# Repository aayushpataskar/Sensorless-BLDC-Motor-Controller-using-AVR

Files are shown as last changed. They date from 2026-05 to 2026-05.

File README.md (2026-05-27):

# Sensorless-BLDC-Motor-Controller-using-AVR
Bare-metal sensorless BLDC motor controller using AVR microcontrollers implementing 6-step trapezoidal commutation, back-EMF zero-crossing detection, PID speed control, PWM generation, current limiting, UVLO protection, and hardware-level motor control architecture.

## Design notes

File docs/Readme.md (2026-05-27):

# Sensorless BLDC Motor Controller — AVR / Arduino UNO

<p align="center">
  ESC Banner
</p>

<p align="center">
  
  
  
  
  
</p>

---

## Overview

This project is a **complete, sensorless Brushless DC (BLDC) motor controller** (Electronic Speed Controller — ESC) implemented from scratch on an **ATmega328P (Arduino UNO R3)** using **bare-metal AVR C** — no Arduino HAL, no motor-control library, no shortcuts.

The controller uses **6-step trapezoidal commutation**, **back-EMF (BEMF) zero-crossing detection** for rotor position sensing, a **PI speed control loop**, and a suite of hardware protection features — all coordinated by a single **interrupt-driven control loop running at ~1 kHz**.

The hardware is designed in **KiCad 9.0** and centres around three **IR2101 half-bridge gate drivers**, six **IRF6617 N-channel MOSFETs**, and an **LM393 dual comparator** for BEMF sensing conditioning.

---

## Key Features

| Feature | Implementation |
|---|---|
| Motor type | 3-phase sensorless BLDC |
| Commutation | 6-step trapezoidal |
| Rotor sensing | Back-EMF zero-crossing detection (software ADC) |
| Gate driving | IR2101 (bootstrap half-bridge × 3 phases) |
| PWM generation | AVR Timer1 (Fast PWM 8-bit) + Timer2 |
| Control loop | Timer0 CTC ISR @ ~1 kHz |
| Speed control | PI controller (proportional + integral) |
| Current limiting | ADC-based with PWM duty-cycle back-off |
| UVLO | Vbus ADC monitoring with hard-fault latch |
| Blanking time | Software blanking window post-commutation |
| Startup | Open-loop forced commutation ramp |
| Schematic | KiCad 9.0 |

---

## Repository Structure

```
sensorless-bldc-avr/
│
├── firmware/
│   └── ESC_using_Arduino.ino       # Main firmware (bare-metal AVR C)
│
├── hardware/
│   ├── esc_using_arduino_uno.kicad_pro
│   └── esc_using_arduino_uno.kicad_sch
│
├── docs/
│   ├── project_overview.md
│   ├── hardware_architecture.md
│   ├── firmware_architecture.md
│   ├── pwm_generation.md
│   ├── adc_and_backemf.md
│   ├── six_step_commutation.md
│   ├── pid_speed_control.md
│   ├── protection_features.md
│   ├── interrupt_architecture.md
│   ├── state_machine.md
│   ├── tuning_and_debugging.md
│   └── future_work.md
│
├── README.md
└── LICENSE
```

---

## Hardware Summary

| Component | Part | Quantity | Role |
|---|---|---|---|
| Microcontroller | Arduino UNO R3 (ATmega328P) | 1 | Control, PWM, ADC |
| Gate driver | IR2101 | 3 | High/low-side MOSFET driving |
| Power MOSFET | IRF6617 | 6 | H-bridge switching (3 half-bridges) |
| Comparator | LM393 (dual) | 1–2 | BEMF signal conditioning |
| Bootstrap diode | 1N5817 (Schottky) | 3 | IR2101 bootstrap charging |
| Gate resistor | 10 Ω | 6 | Switching transition control |
| Pull-down | 10 kΩ | 6 | Gate pull-down |
| Bootstrap cap | 100 nF | 3 | IR2101 bootstrap supply |
| Bulk capacitor | 2.2 mF | 1 | Vbus decoupling |
| Phase resistors | R_Small | 9 | Voltage divider for BEMF sensing |

> See [`docs/hardware_architecture.md`](docs/hardware_architecture.md) for the full schematic walk-through and BOM.

---

## Pin Mapping

| Arduino Pin | AVR Register | Signal | Direction |
|---|---|---|---|
| D9 (OC1A) | PB1 | Phase A — High Side (AH) | Output / PWM |
| D10 (OC1B) | PB2 | Phase B — High Side (BH) | Output / PWM |
| D11 (OC2A) | PB3 | Phase C — High Side (CH) | Output / PWM |
| D4 | PD4 | Phase A — Low Side (AL) | Output / GPIO |
| D7 | PD7 | Phase B — Low Side (BL) | Output / GPIO |
| D8 | PB0 | Phase C — Low Side (CL) | Output / GPIO |
| A0 | ADC0 | Phase A BEMF | Input / ADC |
| A1 | ADC1 | Phase B BEMF | Input / ADC |
| A2 | ADC2 | Phase C BEMF | Input / ADC |
| A3 | ADC3 | Phase current sense | Input / ADC |
| A4 | ADC4 | Vbus voltage sense | Input / ADC |

---

## Quick Start

### Prerequisites

- Arduino IDE 2.x or avr-gcc toolchain
- KiCad 9.0 (for schematic viewing/editing)
- A 3-phase BLDC motor (suitable for target Vbus)

### Building & Flashing

```bash
# Using Arduino IDE
# Open firmware/ESC_using_Arduino.ino → Select "Arduino UNO" → Upload

# Using avr-gcc directly
avr-gcc -mmcu=atmega328p -DF_CPU=16000000UL -O2 -o ESC.elf ESC_using_Arduino.ino
avr-objcopy -O ihex ESC.elf ESC.hex
avrdude -c arduino -p m328p -P /dev/ttyUSB0 -b 115200 -U flash:w:ESC.hex
```

### Key Configuration Parameters

Edit the `CONFIG` block at the top of `ESC_using_Arduino.ino`:

```c
#define NEUTRAL_ADC        512   // Virtual neutral point (midscale)
#define BLANKING_TICKS       5   // ISR ticks to suppress BEMF after commutation
#define CURRENT_LIMIT_ADC  650   // ADC counts → current trip threshold
#define MIN_PWM_DUTY        20   // Minimum duty cycle (stall prevention)
#define MAX_PWM_DUTY       180   // Maximum duty cycle (out of 255)
#define VBUS_MIN_ADC       420   // UVLO trip — Vbus too low
#define START_PERIOD       400   // Open-loop start commutation period (ticks)
#define TARGET_PERIOD      120   // Target commutation period after ramp
float Kp = 0.6f;
float Ki = 20.0f;
float target_speed = 200.0f;    // Desired speed setpoint (arbitrary units)
```

---

## Documentation Index

| Document | Contents |
|---|---|
| [Project Overview](docs/project_overview.md) | System goals, architecture summary, design decisions |
| [Hardware Architecture](docs/hardware_architecture.md) | Gate driver topology, MOSFET selection, BEMF sensing, BOM |
| [Firmware Architecture](docs/firmware_architecture.md) | Code structure, module breakdown, ISR/main interaction |
| [PWM Generation](docs/pwm_generation.md) | Timer1/Timer2 configuration, fast PWM, duty cycle update |
| [ADC & Back-EMF Sensing](docs/adc_and_backemf.md) | ADC configuration, floating phase selection, ZC detection |
| [6-Step Commutation](docs/six_step_commutation.md) | Trapezoidal theory, commutation table, timing diagram |
| [PID Speed Control](docs/pid_speed_control.md) | Speed estimation, PI equations, anti-windup, tuning |
| [Protection Features](docs/protection_features.md) | UVLO, current limiting, blanking time, fault latch |
| [Interrupt Architecture](docs/interrupt_architecture.md) | Timer0 ISR flow, ISR execution budget, latency analysis |
| [State Machine](docs/state_machine.md) | System states, transitions, startup sequence |
| [Tuning & Debugging](docs/tuning_and_debugging.md) | Parameter tuning guide, common failure modes |
| [Future Work](docs/future_work.md) | STM32 migration, FOC, SVPWM, hardware sensors |

---

## Suggested GitHub Topics

`bldc-motor-controller` · `esc` · `sensorless-bldc` · `back-emf` · `zero-crossing-detection` · `avr` · `atmega328p` · `arduino` · `bare-metal` · `motor-control` · `trapezoidal-commutation` · `pwm` · `pid-controller` · `kicad` · `ir2101` · `embedded-c` · `power-electronics`

---

## License

MIT License — see [LICENSE](LICENSE) for details.

---

## Author

Developed as an embedded systems engineering portfolio project.  
Platform: ATmega328P (Arduino UNO R3) · Schematic: KiCad 9.0 · Firmware: Bare-metal AVR C

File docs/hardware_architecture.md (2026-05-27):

# Hardware Architecture

## 1. Overview

The power stage implements a **three-phase voltage-source inverter** using six N-channel MOSFETs arranged as three half-bridges. Each half-bridge drives one motor phase (A, B, C). High-side gate driving is handled by three **IR2101** bootstrap half-bridge gate driver ICs, which solve the floating high-side drive problem without requiring an isolated power supply. BEMF voltage sensing is routed through resistor dividers to the ATmega328P's ADC inputs, with the **LM393** dual comparator available for hardware-assisted zero-crossing detection.

---

## 2. Three-Phase Half-Bridge Topology

```
        Vbus (+)
          │
    ┌─────┼─────┬─────────────┐
    │     │     │             │
   [AH]  [BH]  [CH]           │   (High-side MOSFETs — IRF6617)
    │     │     │             │
   PhA   PhB   PhC ──── BLDC Motor (star-wound)
    │     │     │             │
   [AL]  [BL]  [CL]           │   (Low-side MOSFETs — IRF6617)
    │     │     │             │
    └─────┴─────┴─────────────┘
          │
        GND (-)
```

The motor is assumed to be **star (Y) wound**, producing a virtual neutral point at the junction of the three stator windings. Two phases are driven at any instant (one high, one low) while the third phase floats — this floating phase carries the back-EMF signal used for rotor position estimation.

---

## 3. Gate Driver — IR2101

### 3.1 Why a Gate Driver Is Needed

Power MOSFETs require a gate-to-source voltage (V_GS) of typically 10–12 V to turn on fully into the low-resistance triode region. For low-side MOSFETs, the source is tied to GND, so a logic-level 5 V signal is insufficient (and would result in a partially-on MOSFET with high conduction losses and thermal stress). For high-side MOSFETs, the source sits at the phase output voltage — during conduction it can approach Vbus — so the gate must be driven to V_GS(th) _above_ a floating reference, which the microcontroller cannot do directly.

The **IR2101** solves both problems. It is a monolithic half-bridge driver providing:

- A **low-side output (LO)** referenced to GND — drives the low-side MOSFET gate
- A **high-side output (HO)** referenced to the switch node (VS pin) — drives the high-side MOSFET gate using a bootstrap-charged floating supply

### 3.2 Bootstrap Operation

The bootstrap capacitor (100 nF) is charged through the **1N5817 Schottky diode** when the low-side MOSFET is on: current flows from VCC (5 V) → diode → bootstrap capacitor → VS (switch node at ≈ GND). When the low-side turns off and the high-side is commanded on, the bootstrap capacitor's charged voltage rides up with the switch node and provides the floating supply (V_B) for the high-side driver output. The Schottky diode (low forward voltage, fast recovery) prevents the bootstrap capacitor from discharging back into the VCC rail when VS rises.

```
           VCC (+5V)
              │
             [D: 1N5817 Schottky]
              │
              ├──── VB (IR2101 bootstrap supply)
              │
             [C_boot: 100 nF]
              │
         VS ──┴──── Switch Node (Phase Output)
```

### 3.3 Dead Time

The IR2101 includes internal dead time between its HO and LO outputs, preventing simultaneous conduction of both MOSFETs in a half-bridge (shoot-through). The firmware's `all_off()` function adds a software-level dead band by turning all switches off before applying the next commutation state.

### 3.4 Input Logic

The IR2101 accepts two independent inputs (HIN and LIN) from the microcontroller:

- **HIN** — connected to the PWM output of the corresponding timer channel (OC1A, OC1B, OC2A)
- **LIN** — connected to a GPIO pin (PD4, PD7, PB0) driven directly

The firmware controls whether PWM is active on a given high-side output by enabling or disabling the timer compare output mode bits (`COM1A1`, `COM1B1`, `COM2A1`). When disabled, the pin reverts to GPIO low, which turns off the high-side driver.

---

## 4. Power MOSFETs — IRF6617

The **IRF6617** is an N-channel MOSFET in a DirectFET package. Key parameters relevant to this design:

| Parameter | Value |
|---|---|
| V_DS (max) | 25 V |
| I_D (continuous) | 13 A |
| R_DS(on) @ V_GS = 10 V | ~11 mΩ |
| Gate charge (Q_g) | ~18 nC |
| Package | DirectFET (compact, low-inductance) |

Six devices are used: three high-side (AH, BH, CH) and three low-side (AL, BL, CL).

Gate resistors (R_Small, typically 10 Ω) in series with each gate limit the gate current inrush and control the switching transition speed, reducing EMI and voltage overshoot at the cost of slightly slower switching transitions. Pull-down resistors (10 kΩ) ensure the gate is held low when the driver output is high-impedance (e.g., during startup before the driver IC is enabled).

---

## 5. BEMF Sensing Network

### 5.1 Resistor Divider

Motor phase voltages during operation swing from 0 V to Vbus. The ATmega328P ADC input is limited to 0–5 V (AVCC reference). A resistor divider scales the phase voltage to a safe ADC input range. Three identical dividers (one per phase) feed ADC channels 0, 1, and 2.

```
Phase Voltage (0 → Vbus)
        │
       [R_top]
        │
        ├──── ADC Input (0 → 5 V scaled)
        │
       [R_bot]
        │
       GND
```

The virtual neutral point for zero-crossing comparison is set in firmware as `NEUTRAL_ADC = 512`, corresponding to the midpoint of the 10-bit ADC range (2.5 V on the divided input, which corresponds to Vbus/2 on the phase).

### 5.2 LM393 Comparator Path

The **LM393** dual comparator is schematically connected to compare the BEMF-divided phase voltage against the virtual neutral. Its open-collector output can be connected to a microcontroller GPIO/INT pin for hardware interrupt-driven zero-crossing detection. In the current firmware, this path is not used — zero-crossing is detected in software via the ADC — but the hardware is in place for an upgrade to comparator-interrupt detection (see [`future_work.md`](future_work.md)).

---

## 6. Current Sensing

A shunt resistor in the low-side current path produces a voltage proportional to motor current. This voltage is routed to **ADC channel 3**. The firmware reads this channel each ISR tick and reduces the PWM duty cycle if the ADC count exceeds `CURRENT_LIMIT_ADC = 650`.

> **Note:** A production design would use a dedicated current-sense amplifier (e.g., INA219, INA240) to amplify the small shunt voltage and provide common-mode rejection. The current sensing in this design is approximate.

---

## 7. Vbus Sensing (UVLO)

A resistor divider from the Vbus rail to GND feeds **ADC channel 4**. The firmware monitors this continuously and asserts a fault latch if the reading falls below `VBUS_MIN_ADC = 420`, corresponding to an under-voltage condition on the bus. This protects the power electronics and prevents erratic operation caused by a sagging supply.

---

## 8. Decoupling and Filtering

A bulk electrolytic capacitor (2.2 mF, referenced as `C2.2MF` in the schematic) is placed across the Vbus supply. This capacitor:

- Absorbs current spikes during MOSFET switching transitions
- Reduces ripple on Vbus caused by motor commutation currents
- Stores energy during regenerative braking pulses

Small ceramic decoupling capacitors (100 nF) are placed on each IR2101 VCC and VB pin for high-frequency noise bypass.

---

## 9. Bill of Materials (BOM)

| Reference | Value / Part | Description | Qty |
|---|---|---|---|
| U1, U2, U3 | IR2101 | Half-bridge MOSFET gate driver | 3 |
| Q1–Q6 | IRF6617 | N-channel power MOSFET | 6 |
| U4 | LM393 | Dual voltage comparator | 1 |
| A1 | Arduino UNO R3 | ATmega328P control module | 1 |
| D1, D2, D3 | 1N5817 | Schottky bootstrap diode | 3 |
| C1, C2, C3 | 100 nF (ceramic) | Bootstrap capacitor | 3 |
| C4 | 2.2 mF (electrolytic) | Vbus bulk decoupling | 1 |
| R1–R6 | 10 Ω | Gate resistors | 6 |
| R7–R12 | 10 kΩ | Gate pull-downs | 6 |
| R13–R18 | R_Small (see note) | BEMF voltage divider resistors | 9 |
| R_SHUNT | R_Small | Current sense shunt | 1 |
| R_VBUS | 10 kΩ / R_Small pair | Vbus sense divider | 2 |

> Resistor values for the BEMF dividers and Vbus divider should be calculated for the specific Vbus operating voltage to ensure the divided signal fits within the 0–5 V ADC input range.

---

## 10. Schematic Navigation (KiCad)

Open `hardware/esc_using_arduino_uno.kicad_sch` in KiCad 9.0. The schematic is organised as follows:

- **Top section**: Vbus input, bulk capacitor, three half-bridge legs (IR2101 + MOSFET pairs)
- **Middle section**: Arduino UNO module with PWM and GPIO connections to gate drivers
- **Bottom section**: BEMF sensing resistor dividers, LM393 comparator circuit, ADC connections
- **Right section**: Current sense and Vbus sense circuits

The KiCad project file (`esc_using_arduino_uno.kicad_pro`) contains ERC rule settings and net class definitions.

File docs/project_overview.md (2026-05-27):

# Project Overview

## 1. Purpose and Motivation

This project implements a complete **sensorless Electronic Speed Controller (ESC)** for a three-phase Brushless DC (BLDC) motor, built entirely on an ATmega328P microcontroller (Arduino UNO R3) using bare-metal AVR C. The goal was to understand and implement every layer of a real motor controller — from register-level timer configuration and interrupt-driven control loops, to back-EMF zero-crossing detection, six-step commutation sequencing, and closed-loop PI speed regulation — without relying on any motor-control library or high-level abstraction.

BLDC motors are preferred in applications such as drones, electric vehicles, robotic actuators, and industrial drives because of their high efficiency, high power density, and low maintenance profile (no brushes to wear). Driving them correctly, however, requires precise rotor-position knowledge and fast switching logic. High-performance applications use dedicated hardware sensors (Hall-effect, encoders, resolvers); sensorless controllers infer rotor position from the motor's own back-electromotive force (back-EMF), reducing cost and mechanical complexity at the expense of firmware sophistication.

This project demonstrates the full sensorless drive chain on constrained 8-bit hardware — a deliberate choice that forces careful management of ISR timing, ADC scheduling, and CPU budget.

---

## 2. System Architecture Summary

The system consists of two interacting domains: the **power stage**, which switches motor phase currents at voltages up to the Vbus rail, and the **control domain**, running on the ATmega328P at 5 V logic.

```
┌────────────────────────────────────────────────────────────────┐
│                        POWER STAGE                             │
│                                                                │
│   Vbus ──┬── [AH: IRF6617] ──┬──── Phase A                    │
│          │   [AL: IRF6617] ──┘         │                       │
│          ├── [BH: IRF6617] ──┬──── Phase B   ← BLDC Motor     │
│          │   [BL: IRF6617] ──┘         │                       │
│          └── [CH: IRF6617] ──┬──── Phase C                    │
│              [CL: IRF6617] ──┘                                 │
└───────────────────────┬────────────────────────────────────────┘
                        │ Gate drive signals (IR2101 × 3)
┌───────────────────────▼────────────────────────────────────────┐
│                     CONTROL DOMAIN (ATmega328P)                │
│                                                                │
│  Timer1 / Timer2  →  High-side PWM (OC1A, OC1B, OC2A)         │
│  GPIO (PD4,PD7,PB0) → Low-side enable                          │
│  ADC (CH0–2)       →  Back-EMF floating phase sensing          │
│  ADC (CH3)         →  Phase current monitoring                 │
│  ADC (CH4)         →  Vbus voltage monitoring (UVLO)           │
│  Timer0 ISR        →  1 kHz control tick                       │
│    ├─ UVLO check                                               │
│    ├─ Current limit                                            │
│    ├─ Speed ramp                                               │
│    ├─ Speed estimation                                         │
│    ├─ PI update → PWM duty cycle                               │
│    └─ BEMF zero-crossing → commutation                         │
└────────────────────────────────────────────────────────────────┘
```

---

## 3. Design Decisions

### 3.1 Bare-Metal AVR C

The firmware is written against AVR hardware registers directly (`TCCR1A`, `ADMUX`, `OCR1A`, etc.) rather than the Arduino HAL. This was intentional: understanding the exact timer prescaler values, ADC conversion timing, interrupt vector configuration, and GPIO register mappings is essential for a functioning motor controller. The Arduino HAL adds indirection and timing uncertainty that is acceptable for general I/O but problematic for motor control.

### 3.2 Software Back-EMF Detection vs. Hardware Comparator

The schematic includes an **LM393 dual comparator**, which can be used for hardware zero-crossing detection. In the current firmware, zero-crossing detection is performed in software by the ADC: the floating phase voltage is sampled and compared against a 512-count virtual neutral (midscale of a 10-bit ADC with 5 V reference). This avoids needing a comparator interrupt but consumes ADC conversion time within the ISR. The LM393 path is present for a future upgrade to comparator-interrupt-driven ZC detection, which would improve timing accuracy at higher speeds.

### 3.3 Single-ISR Architecture

All time-critical operations — UVLO check, current limit, speed ramp, speed estimation, PI update, BEMF polling, and commutation triggering — are consolidated into a **single Timer0 compare-match ISR**. This eliminates inter-ISR priority conflicts and makes execution order deterministic. The trade-off is that the ISR must complete within one timer period (~100 µs at the configured prescaler and compare value).

### 3.4 PI Controller Without Derivative Term

A full PID controller was considered but the derivative term was omitted for two reasons. First, speed estimation from zero-crossing timing is inherently noisy on 8-bit hardware, and the derivative of a noisy signal produces excessive duty-cycle jitter. Second, BLDC speed response is dominated by inertia and back-EMF, making the PI response sufficient for smooth closed-loop operation. The derivative term can be added once speed estimation is filtered.

### 3.5 Open-Loop Startup Ramp

Sensorless back-EMF detection is unreliable at standstill and very low speeds because back-EMF magnitude is proportional to rotor velocity (V_BEMF = K_e × ω). The firmware therefore starts the motor with an open-loop forced-commutation sequence at a long initial period (`START_PERIOD = 400` ticks), then linearly shortens the period (`RAMP_RATE = 1` tick per `RAMP_INTERVAL = 20` ISR ticks) until the target period is reached. At that point, back-EMF amplitude is sufficient for reliable zero-crossing detection and the loop transitions to closed-loop operation.

---

## 4. Scope and Limitations

This implementation is an educational and portfolio-grade proof-of-concept. The following limitations apply:

- The ATmega328P's 10-bit ADC and 8-bit timer resolution constrain speed estimation accuracy and PWM resolution.
- The software zero-crossing detection is susceptible to ADC noise; hardware comparator detection (via the LM393) is more robust.
- The PI controller's floating-point arithmetic is computationally expensive on an 8-bit MCU; a fixed-point implementation would be preferable in production.
- No fault recovery logic is implemented; once a fault latch is set (e.g., UVLO), the motor remains disabled until a hardware reset.
- The current sensing circuit measures a proxy signal; a proper shunt + op-amp circuit with calibration would be required for accurate current measurement.

---

## 5. Intended Audience

This documentation is written for:

- Embedded systems engineers and students studying motor control
- Makers building their own ESC hardware
- Engineers evaluating the project for further development (STM32 migration, FOC upgrade)
- Anyone interested in understanding what happens inside a commercial ESC at the register level

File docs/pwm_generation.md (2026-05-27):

# PWM Generation

## 1. Background — Why PWM for Motor Control

A BLDC motor is driven by controlling the average voltage applied to each phase. Since the gate drivers and MOSFETs are switching devices (on or off), average voltage control is achieved through **Pulse-Width Modulation (PWM)**: the high-side MOSFET for the active phase is rapidly switched on and off at a fixed frequency, and the ratio of on-time to total period (duty cycle, D) sets the average phase voltage:

```
V_phase_avg = D × V_bus,    where D = OCR / 255   (for 8-bit Fast PWM)
```

A higher duty cycle means more average voltage, which drives more current through the motor windings and produces more torque and speed.

---

## 2. Timer Configuration

The ATmega328P has three hardware timers available: Timer0 (8-bit), Timer1 (16-bit), and Timer2 (8-bit). In this design:

| Timer | Role | Mode | Output Channels Used |
|---|---|---|---|
| Timer0 | Control tick ISR | CTC (Clear Timer on Compare) | None (ISR only) |
| Timer1 | PWM for Phase A and B high-side | Fast PWM 8-bit (WGM = 0b101) | OC1A (PB1/D9), OC1B (PB2/D10) |
| Timer2 | PWM for Phase C high-side | Fast PWM (WGM = 0b11) | OC2A (PB3/D11) |

Timer0 is deliberately kept separate from the PWM timers so that the control ISR frequency is independent of the PWM frequency.

---

## 3. Timer1 — Fast PWM 8-bit

### Register Configuration

```c
// Fast PWM 8-bit: WGM1[2:0] = 0b101 (WGM10 + WGM12)
TCCR1A = (1 << WGM10);                       // WGM10 = 1
TCCR1B = (1 << WGM12) | (1 << CS11);         // WGM12 = 1, prescaler /8
```

**Waveform Generation Mode (WGM):**

| Bit | WGM12 | WGM11 | WGM10 | Mode |
|---|---|---|---|---|
| Value | 1 | 0 | 1 | Fast PWM, 8-bit (TOP = 0xFF = 255) |

In Fast PWM mode, the counter increments from BOTTOM (0x00) to TOP (0xFF), then resets immediately to BOTTOM. The output compare pin is set at BOTTOM and cleared when the counter matches OCRnX (non-inverting mode, COM1A1=1, COM1B1=1).

**Prescaler Selection (CS11 = 1 → /8):**

```
f_PWM = f_CPU / (prescaler × (TOP + 1))
      = 16,000,000 / (8 × 256)
      = 7,812.5 Hz ≈ 7.8 kHz
```

A PWM frequency of ~7.8 kHz is above the audible range (> 20 kHz is ideal, but 7.8 kHz reduces audible switching noise sufficiently for most applications) while keeping switching losses manageable with the IRF6617's gate charge.

**Compare Output Mode:**

The `AH_ON()` and `BH_ON()` macros set `COM1A1` and `COM1B1` respectively, connecting OC1A/OC1B to their output pins in non-inverting fast PWM mode. `AH_OFF()` and `BH_OFF()` clear these bits, disconnecting the PWM and driving the pin low — effectively turning off the high-side gate driver input.

```c
#define AH_ON()   (TCCR1A |=  (1 << COM1A1))   // OC1A → PWM output
#define AH_OFF()  (TCCR1A &= ~(1 << COM1A1))   // OC1A → GPIO low
```

This mechanism is the key insight of the commutation implementation: rather than reconfiguring timer hardware between steps, the firmware simply connects or disconnects the already-running PWM output to the pin.

---

## 4. Timer2 — Fast PWM

```c
// Fast PWM: WGM2[1:0] = 0b11 (WGM20 + WGM21), prescaler /8
TCCR2A = (1 << WGM20) | (1 << WGM21);        // Fast PWM, TOP = 0xFF
TCCR2B = (1 << CS21);                         // prescaler /8
```

Timer2 mirrors Timer1's PWM parameters for Phase C (OC2A, PB3/D11). Both timers run at the same nominal frequency (~7.8 kHz), which is desirable to keep all three phases switching in phase — though Timer1 and Timer2 are not hardware-synchronised in this design and will accumulate phase drift over time. A future improvement would synchronise the two timers' counter values at startup.

---

## 5. Duty Cycle Update

The duty cycle is stored in the global `pwm_duty` variable (0–255) and written to all three compare registers simultaneously during the ISR:

```c
OCR1A = pwm_duty;   // Phase A high-side
OCR1B = pwm_duty;   // Phase B high-side
OCR2A = pwm_duty;   // Phase C high-side
```

Since only one high-side is active at any commutation step, writing to all three registers is safe — the inactive channels are disconnected from their pins by the `AH_OFF()`/`BH_OFF()`/`CH_OFF()` macros.

**Duty cycle is bounded:**

```c
if (pwm_duty > MAX_PWM_DUTY) pwm_duty = MAX_PWM_DUTY;   // 180 / 255 ≈ 70.6%
if (pwm_duty < MIN_PWM_DUTY) pwm_duty = MIN_PWM_DUTY;   // 20  / 255 ≈  7.8%
```

The maximum duty cycle is intentionally limited to 180/255 to prevent the bootstrap capacitor from discharging completely (the low-side must turn on periodically to recharge the bootstrap capacitor; a 100% duty cycle would starve the bootstrap supply and cause gate drive failure).

---

## 6. Low-Side Drive — GPIO

The low-side MOSFETs (AL, BL, CL) are driven directly by GPIO pins. Since the low-side source is tied to GND, a 5 V logic signal provides adequate V_GS to drive the IR2101 LIN input. The low-side is either fully on or fully off — PWM is only applied to the high side (asymmetric PWM, complementary to the high-side PWM). This is a common simplification for trapezoidal control.

```c
#define AL_ON()   (PORTD |=  (1 << PD4))
#define AL_OFF()  (PORTD &= ~(1 << PD4))
```

---

## 7. PWM Timing Diagram (Single Step)

```
                  PWM Period (~128 µs @ 7.8 kHz)
          │◄─────────────────────────────────────►│
          │                                        │
High-side │▓▓▓▓▓▓▓▓▓▓▓▓▓▓▓▓▓▓▓▓▓▓▓▓░░░░░░░░░░░░░│▓▓...
(e.g. AH) │ ON (OCR counts)          OFF            │
          │                                        │
Low-side  │▓▓▓▓▓▓▓▓▓▓▓▓▓▓▓▓▓▓▓▓▓▓▓▓▓▓▓▓▓▓▓▓▓▓▓▓▓▓▓│▓▓...
(e.g. BL) │ ALWAYS ON during this step             │
          │                                        │
Phase C   │░░░░░░░░░░░░░░░░░░░░░░░░░░░░░░░░░░░░░░░│...
(floating)│ FLOATING — BEMF measurable here        │
```

The floating phase carries the back-EMF voltage which crosses the virtual neutral at the zero-crossing point used for commutation timing.

---

## 8. Timer0 — Control Tick

Timer0 operates in **CTC (Clear Timer on Compare) mode**:

```c
TCCR0A = (1 << WGM01);                         // CTC mode
TCCR0B = (1 << CS01) | (1 << CS00);            // prescaler /64
OCR0A  = 200;                                   // Compare value
TIMSK0 = (1 << OCIE0A);                         // Enable compare-match interrupt
```

ISR period:

```
f_ISR  = f_CPU / (prescaler × (OCR0A + 1))
       = 16,000,000 / (64 × 201)
       ≈ 1,245 Hz
T_ISR  ≈ 803 µs
```

This ~1.25 kHz tick drives all control and monitoring functions. It is entirely independent of the PWM frequency, which is correct — the PWM runs continuously at 7.8 kHz while the control loop updates duty cycle at ~1.25 kHz.

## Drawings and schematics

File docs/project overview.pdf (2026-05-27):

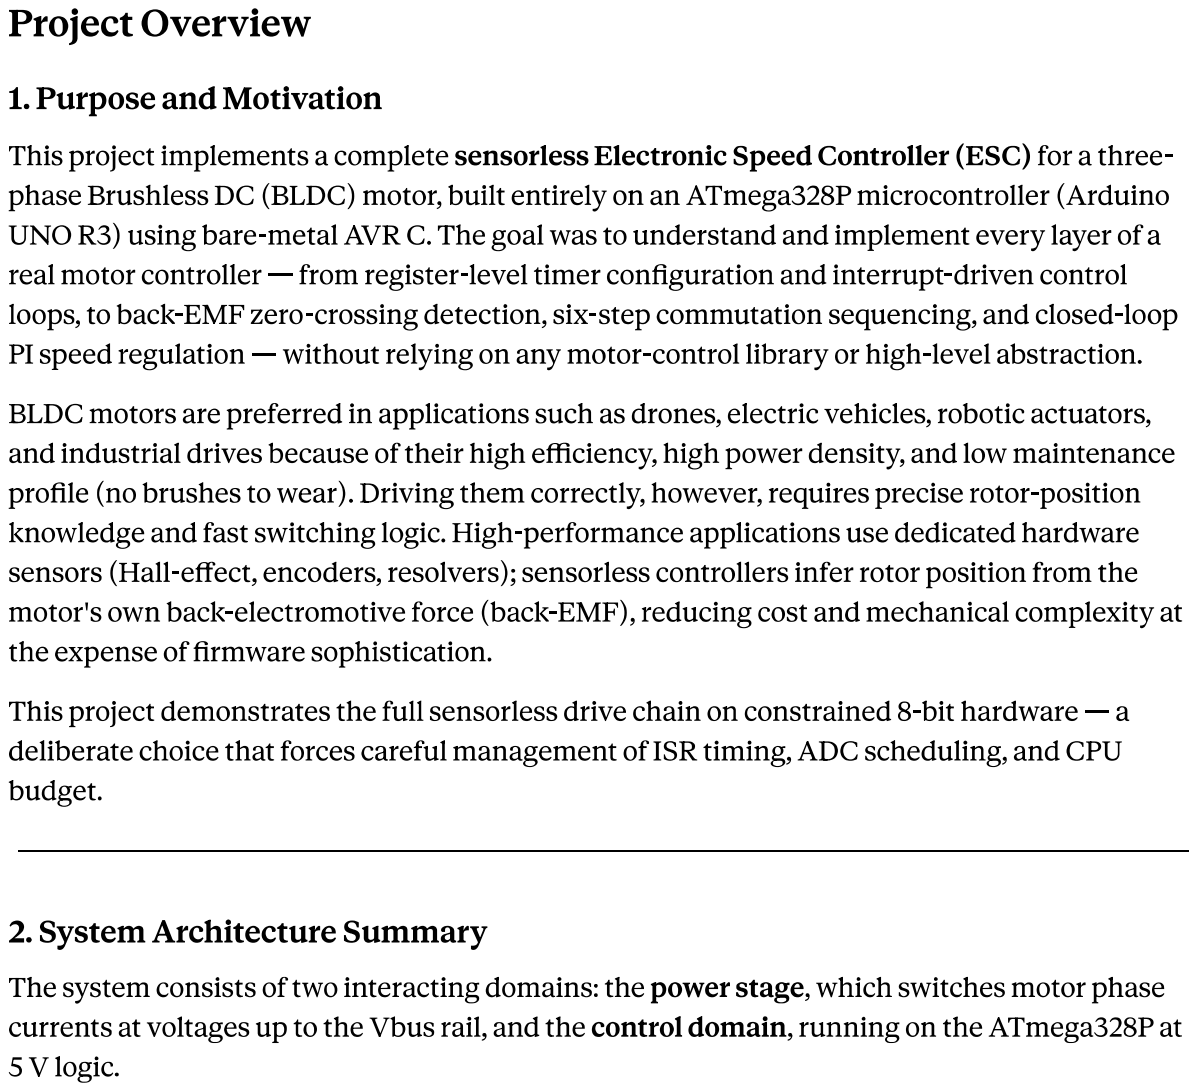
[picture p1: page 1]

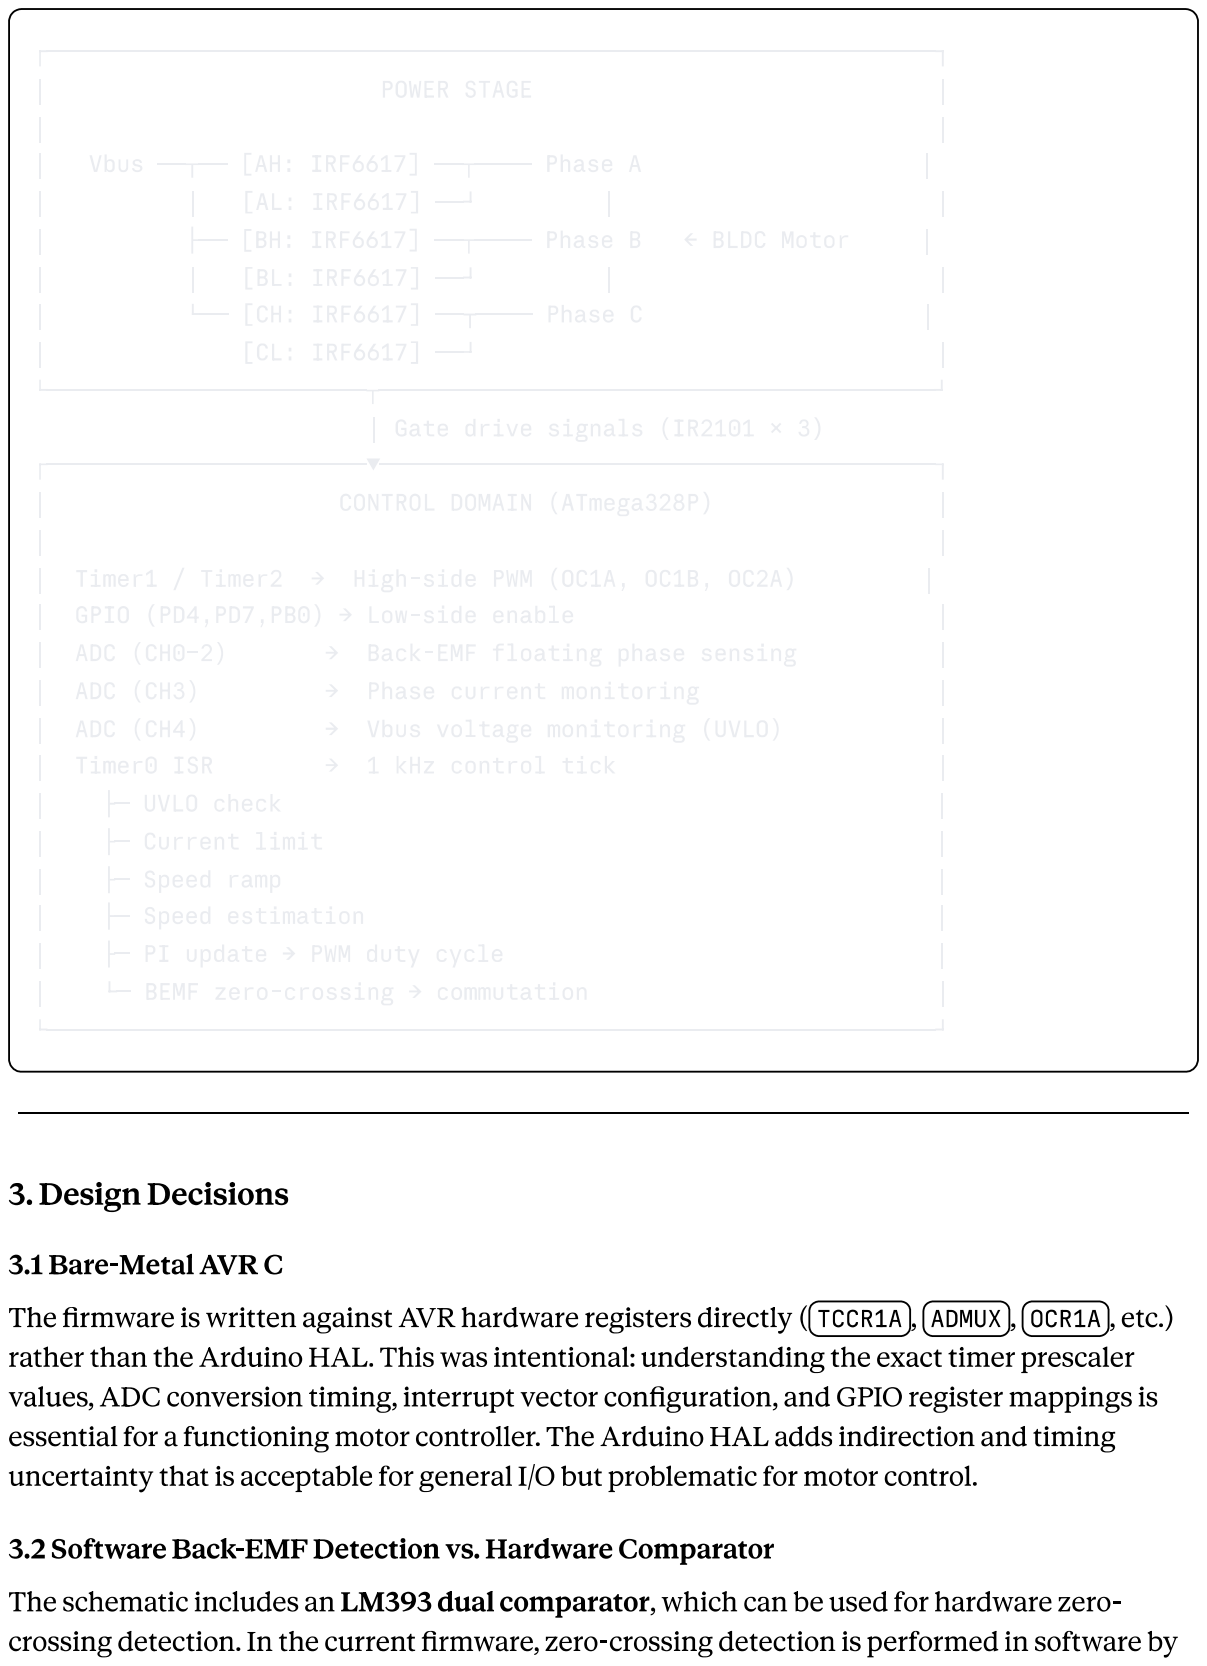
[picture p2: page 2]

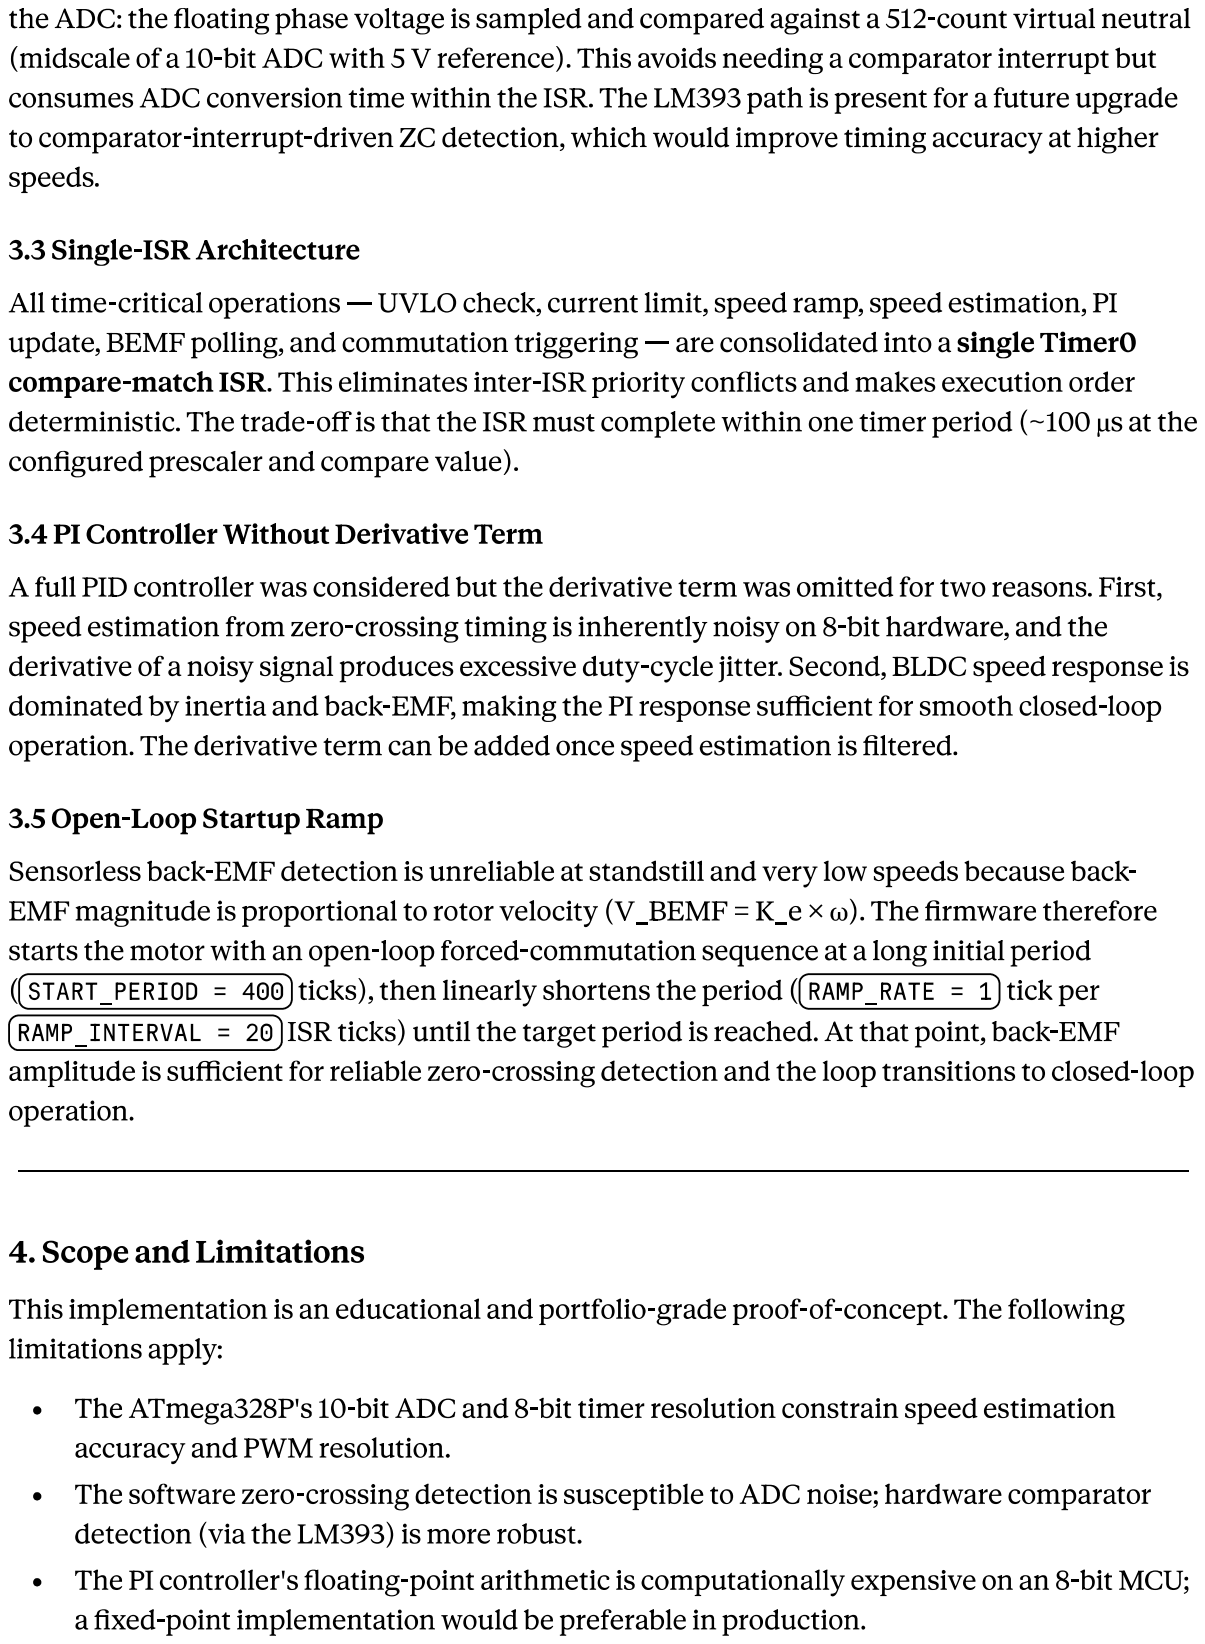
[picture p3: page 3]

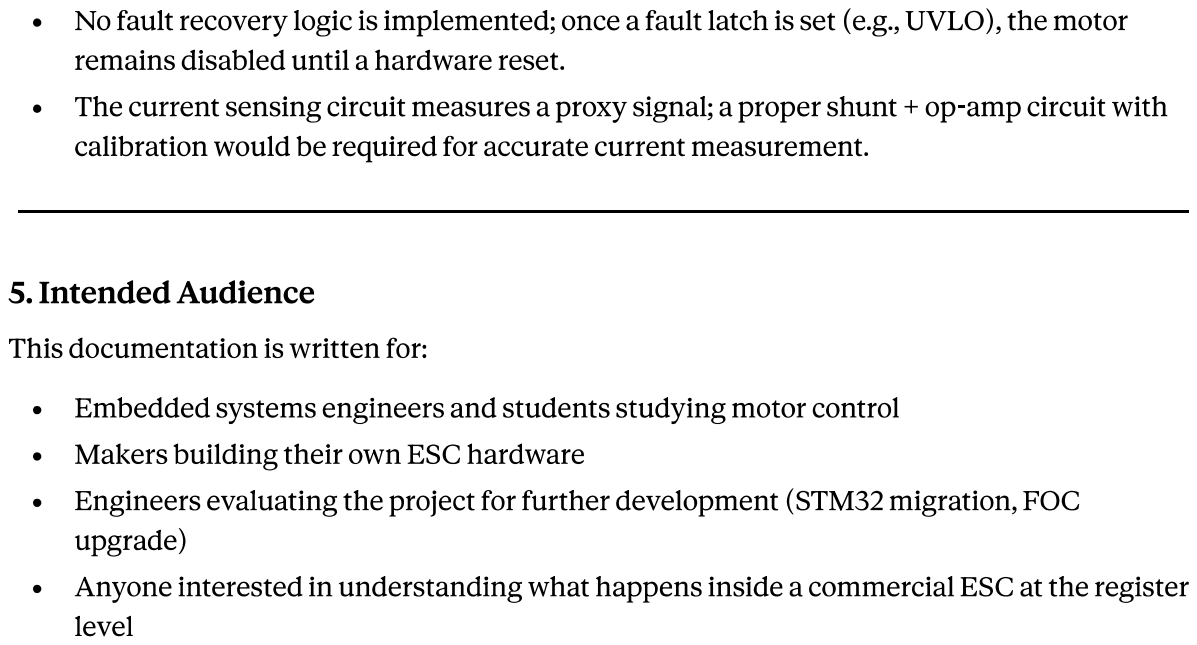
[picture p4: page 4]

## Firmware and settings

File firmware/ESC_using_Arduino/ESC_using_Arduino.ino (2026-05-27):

#include <avr/io.h>
#include <avr/interrupt.h>
#include <stdint.h>

/* ---------------- CONFIG ---------------- */

#define NEUTRAL_ADC        512
#define BLANKING_TICKS    5

#define CURRENT_LIMIT_ADC 650
#define MIN_PWM_DUTY      20
#define MAX_PWM_DUTY      180

/* -------- SPEED RAMP CONFIG -------- */
#define START_PERIOD   400
#define TARGET_PERIOD  120
#define RAMP_RATE      1
#define RAMP_INTERVAL  20

/* -------- UVLO CONFIG -------- */
#define VBUS_ADC_CH     4
#define VBUS_MIN_ADC   420

/* -------- PID CONFIG -------- */
#define PID_DT         0.001f   // 1 ms loop

float Kp = 0.6f;
float Ki = 20.0f;

/* ---------------- GLOBALS ---------------- */

volatile uint8_t step = 1;

volatile uint16_t zc_time = 0;
volatile uint8_t  zc_detected = 0;

volatile uint8_t blanking_active = 0;
volatile uint8_t blanking_count  = 0;

volatile uint8_t pwm_duty = 80;

/* ---- SPEED RAMP ---- */
volatile uint16_t comm_period = START_PERIOD;
volatile uint16_t ramp_counter = 0;

/* ---- FAULT FLAG ---- */
volatile uint8_t fault = 0;

/* ---- PID STATE ---- */
float pid_integral = 0;
float target_speed = 200.0f;     // arbitrary units
float speed_est    = 0;

/* ---------------- PWM MACROS ---------------- */

#define AH_ON()   (TCCR1A |=  (1 << COM1A1))
#define AH_OFF()  (TCCR1A &= ~(1 << COM1A1))

#define BH_ON()   (TCCR1A |=  (1 << COM1B1))
#define BH_OFF()  (TCCR1A &= ~(1 << COM1B1))

#define CH_ON()   (TCCR2A |=  (1 << COM2A1))
#define CH_OFF()  (TCCR2A &= ~(1 << COM2A1))

/* ---------------- LOW SIDE GPIO ---------------- */

#define AL_ON()   (PORTD |=  (1 << PD4))
#define AL_OFF()  (PORTD &= ~(1 << PD4))

#define BL_ON()   (PORTD |=  (1 << PD7))
#define BL_OFF()  (PORTD &= ~(1 << PD7))

#define CL_ON()   (PORTB |=  (1 << PB0))
#define CL_OFF()  (PORTB &= ~(1 << PB0))

/* ---------------- SAFETY OFF ---------------- */

void all_off(void)
{
    AH_OFF(); BH_OFF(); CH_OFF();
    AL_OFF(); BL_OFF(); CL_OFF();
}

/* ---------------- PWM INIT ---------------- */

void pwm_init(void)
{
    DDRB |= (1 << PB1) | (1 << PB2) | (1 << PB3);
    DDRD |= (1 << PD4) | (1 << PD7);
    DDRB |= (1 << PB0);

    // TIMER1 – Fast PWM 8-bit
    TCCR1A = (1 << WGM10);
    TCCR1B = (1 << WGM12) | (1 << CS11);

    // TIMER2 – Fast PWM
    TCCR2A = (1 << WGM20) | (1 << WGM21);
    TCCR2B = (1 << CS21);

    OCR1A = pwm_duty;
    OCR1B = pwm_duty;
    OCR2A = pwm_duty;

    all_off();
}

/* ---------------- COMMUTATION ---------------- */

void commutate(uint8_t s)
{
    if (fault) return;

    all_off();

    switch (s)
    {
        case 1: AH_ON(); BL_ON(); break;
        case 2: AH_ON(); CL_ON(); break;
        case 3: BH_ON(); CL_ON(); break;
        case 4: BH_ON(); AL_ON(); break;
        case 5: CH_ON(); AL_ON(); break;
        case 6: CH_ON(); BL_ON(); break;
    }

    blanking_active = 1;
    blanking_count  = 0;
}

/* ---------------- ADC ---------------- */

void adc_init(void)
{
    ADMUX = (1 << REFS0);
    ADCSRA = (1 << ADEN) |
             (1 << ADPS2) | (1 << ADPS1) | (1 << ADPS0);
}

uint16_t adc_read(uint8_t ch)
{
    ADMUX = (ADMUX & 0xF0) | (ch & 0x0F);
    ADCSRA |= (1 << ADSC);
    while (ADCSRA & (1 << ADSC));
    return ADC;
}

/* ---------------- FLOATING PHASE MAP ---------------- */

uint8_t floating_phase_adc(uint8_t s)
{
    switch (s)
    {
        case 1: return 2;
        case 2: return 1;
        case 3: return 0;
        case 4: return 2;
        case 5: return 1;
        case 6: return 0;
    }
    return 0;
}

/* ---------------- ZC DETECTION ---------------- */

uint8_t detect_zc(uint8_t ch)
{
    static int16_t prev_error = 0;

    int16_t v = adc_read(ch);
    int16_t error = v - NEUTRAL_ADC;

    if ((prev_error < 0 && error > 0) ||
        (prev_error > 0 && error < 0))
    {
        prev_error = error;
        return 1;
    }

    prev_error = error;
    return 0;
}

/* ---------------- CURRENT LIMIT ---------------- */

void current_limit_check(void)
{
    uint16_t cur = adc_read(3);

    if (cur > CURRENT_LIMIT_ADC)
    {
        if (pwm_duty > MIN_PWM_DUTY)
            pwm_duty--;

        OCR1A = pwm_duty;
        OCR1B = pwm_duty;
        OCR2A = pwm_duty;
    }
}

/* ---------------- UVLO ---------------- */

void uvlo_check(void)
{
    uint16_t vbus = adc_read(VBUS_ADC_CH);

    if (vbus < VBUS_MIN_ADC)
    {
        all_off();
        fault = 1;
    }
}

/* ---------------- SPEED ESTIMATION ---------------- */

float compute_speed(void)
{
    if (zc_time == 0) return 0;
    return 1000.0f / zc_time;   // scaled speed
}

/* ---------------- PID ---------------- */

float pid_update(float target, float measured)
{
    float error = target - measured;

    pid_integral += error * PID_DT;

    // anti-windup
    if (pid_integral >  200) pid_integral =  200;
    if (pid_integral < -200) pid_integral = -200;

    return (Kp * error) + (Ki * pid_integral);
}

/* ---------------- TIMER0 ---------------- */

void timer0_init(void)
{
    TCCR0A = (1 << WGM01);
    TCCR0B = (1 << CS01) | (1 << CS00);
    OCR0A  = 200;
    TIMSK0 = (1 << OCIE0A);
}

/* ---------------- ISR ---------------- */

ISR(TIMER0_COMPA_vect)
{
    static uint16_t counter = 0;

    /* ---- BLANKING ---- */
    if (blanking_active)
    {
        blanking_count++;
        if (blanking_count >= BLANKING_TICKS)
            blanking_active = 0;
        return;
    }

    /* ---- UVLO ---- */
    uvlo_check();
    if (fault) return;

    /* ---- CURRENT LIMIT ---- */
    current_limit_check();

    /* ---- SPEED RAMP ---- */
    ramp_counter++;
    if (ramp_counter >= RAMP_INTERVAL)
    {
        ramp_counter = 0;
        if (comm_period > TARGET_PERIOD)
            comm_period -= RAMP_RATE;
    }

    /* ---- SPEED ESTIMATE ---- */
    speed_est = compute_speed();

    /* ---- PID CONTROL ---- */
    float pid_out = pid_update(target_speed, speed_est);

    pwm_duty += (int)pid_out;

    if (pwm_duty > MAX_PWM_DUTY) pwm_duty = MAX_PWM_DUTY;
    if (pwm_duty < MIN_PWM_DUTY) pwm_duty = MIN_PWM_DUTY;

    OCR1A = pwm_duty;
    OCR1B = pwm_duty;
    OCR2A = pwm_duty;

    /* ---- SENSORLESS CORE ---- */

    uint8_t adc_ch = floating_phase_adc(step);

    if (!zc_detected)
    {
        if (detect_zc(adc_ch))
        {
            zc_time = counter;
            counter = 0;
            zc_detected = 1;
        }
    }
    else
    {
        if (counter >= zc_time)
        {
            step++;
            if (step > 6) step = 1;
            commutate(step);

            zc_detected = 0;
            counter = 0;
        }
    }

    counter++;
}

/* ---------------- MAIN ---------------- */

int main(void)
{
    pwm_init();
    adc_init();
    timer0_init();

    commutate(step);
    sei();

    while (1)
    {
        // everything runs in ISR
    }
}
